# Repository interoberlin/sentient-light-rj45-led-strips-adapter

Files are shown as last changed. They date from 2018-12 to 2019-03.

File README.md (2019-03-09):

# sentient-light-rj45-led-strips-adapter

The adapter receives four data signals via an off-the-shelf RJ-45 ethernet socket
and routes them to a 1x5-pin header as well as to LED strip solder pads.
The adapter is intended for usage with strips of addressable LEDs (e.g. WS2812 or SK6812).

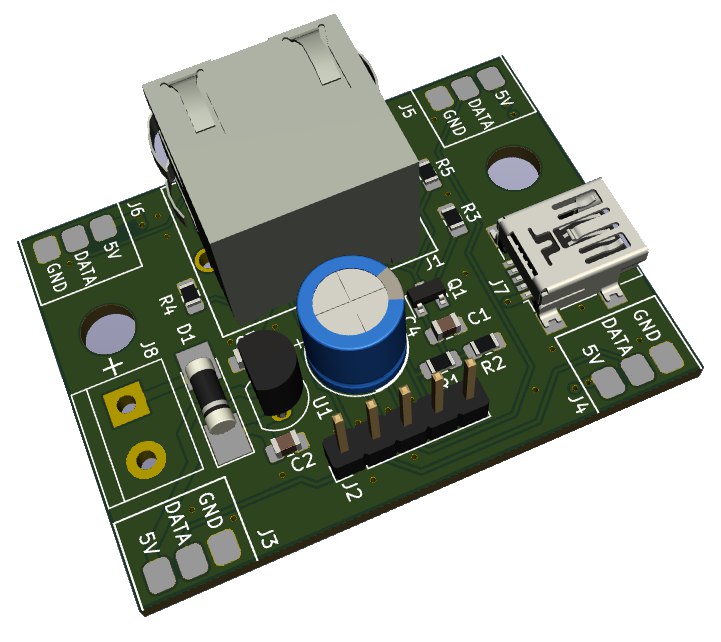
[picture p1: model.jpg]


## Original design goals

* The 1x5-pin header must match the pin layout previously used in this project:
  * https://github.com/interoberlin/Baumhaus-Tree-Adapter
* The RJ-45 socket pins assignment must match the one used in this project:
  * https://github.com/interoberlin/sentient-light-fpga-rj45-adapter
* The PCB should have holes suitable for (wall) mounting.
* It should be possible to attach a 5V supply to the board, e.g. via USB, screw socket or barrel jack socket.
* A high current-capable diode should protect against incorrect supply voltage polarization.
* One LED of the RJ-45 socket should announce the presence of the 5V supply voltage.
* The second LED should light up, when data is received on one of the four signal lines.
* Footprints should be present for one or more 5V LDOs (depending on the required LED current).

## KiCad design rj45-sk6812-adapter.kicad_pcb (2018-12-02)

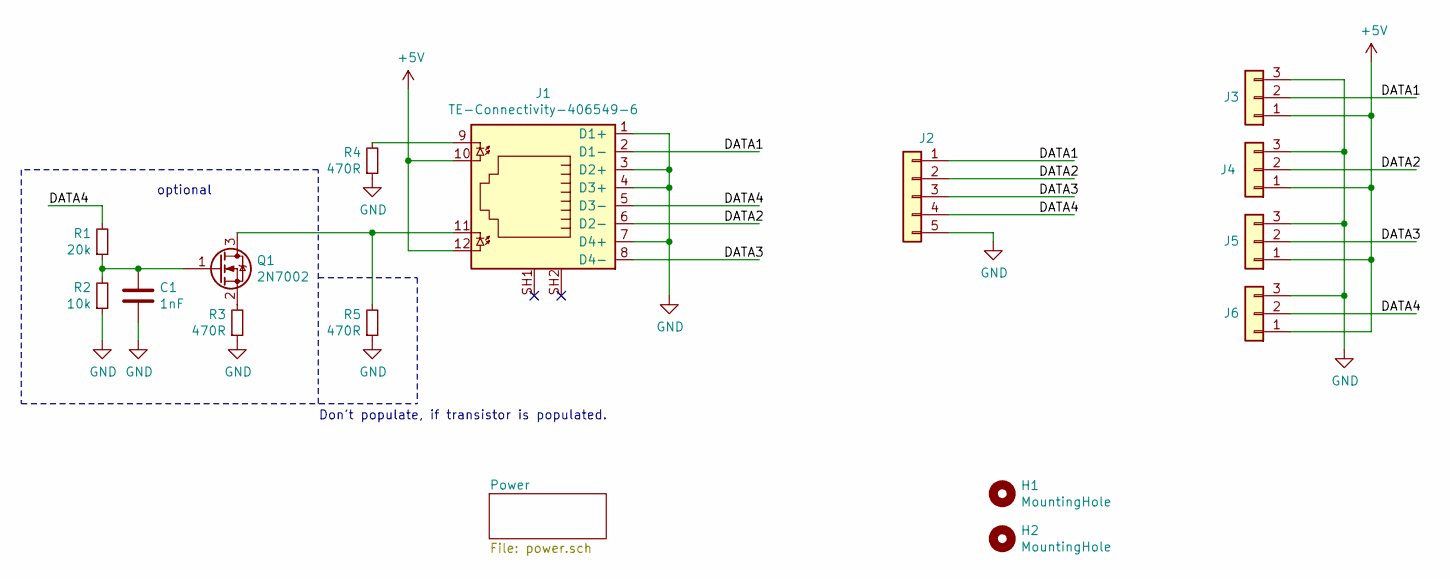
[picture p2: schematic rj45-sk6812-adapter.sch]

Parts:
C1: 1nF; C_0805_2012Metric_Pad1.15x1.40mm_HandSolder
H1, H2: MountingHole; MountingHole_4.5mm
J1: TE-Connectivity-406549-6
J2: Conn_01x05; PinHeader_1x05_P2.54mm_Vertical
J3, J4, J5, J6: Conn_01x03; WS6812-SK6812
Q1: 2N7002; SOT-23
R1: 20k; R_0805_2012Metric_Pad1.15x1.40mm_HandSolder
R2: 10k; R_0805_2012Metric_Pad1.15x1.40mm_HandSolder
R3, R4, R5: 470R; R_0805_2012Metric_Pad1.15x1.40mm_HandSolder

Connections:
+5V: J1.10, J1.12, J3.1, J4.1, J5.1, J6.1; also elsewhere on the board
/DATA1: J1.2 (D1-), J2.1, J3.2
/DATA2: J1.6 (D2-), J2.2, J4.2
/DATA3: J1.8 (D4-), J2.3, J5.2
/DATA4: J1.5 (D3-), J2.4, J6.2, R1.2
GND: C1.2, J1.1 (D1+), J1.3 (D2+), J1.4 (D3+), J1.7 (D4+), J2.5, J3.3, J4.3, J5.3, J6.3, R2.1, R3.1, R4.1, R5.1; also elsewhere on the board
unnamed: C1.1, Q1.1 (G), R1.1, R2.2
unnamed: J1.9, R4.2
unnamed: J1.11, Q1.3 (D), R5.2
unnamed: Q1.2 (S), R3.2

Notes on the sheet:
optional
Don't populate, if transistor is populated.

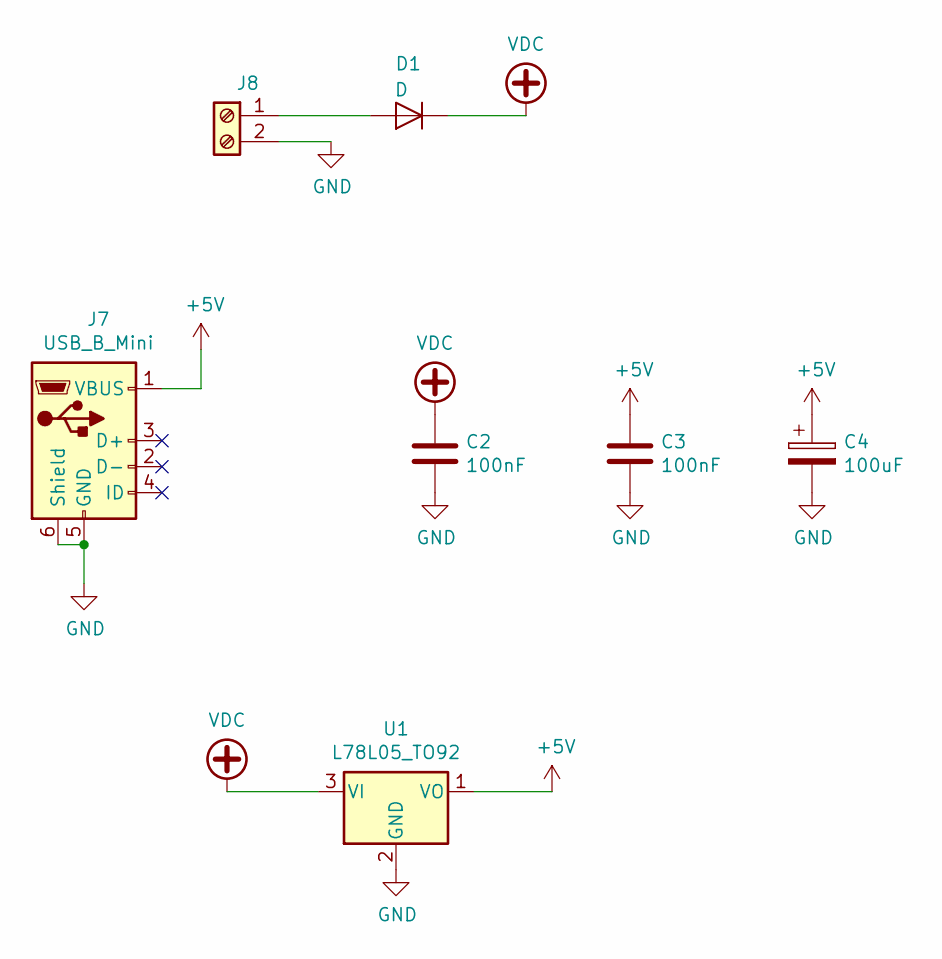
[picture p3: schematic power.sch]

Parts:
C2, C3: 100nF; C_0805_2012Metric_Pad1.15x1.40mm_HandSolder
C4: 100uF; CP_Radial_D8.0mm_P3.80mm
D1: D; D_MELF_Handsoldering
J7: USB_B_Mini; USB_Mini-B_Lumberg_2486_01_Horizontal
J8: Screw_Terminal_01x02; TerminalBlock_bornier-2_P5.08mm
U1: L78L05_TO92; TO-92_Inline

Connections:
+5V: C3.1, C4.1, J7.1 (VBUS), U1.1 (VO); also elsewhere on the board
GND: C2.2, C3.2, C4.2, J7.5 (GND), J7.6 (Shield), J8.2, U1.2 (GND); also elsewhere on the board
unnamed: D1.2 (A), J8.1
VDC: C2.1, D1.1 (K), U1.3 (VI)

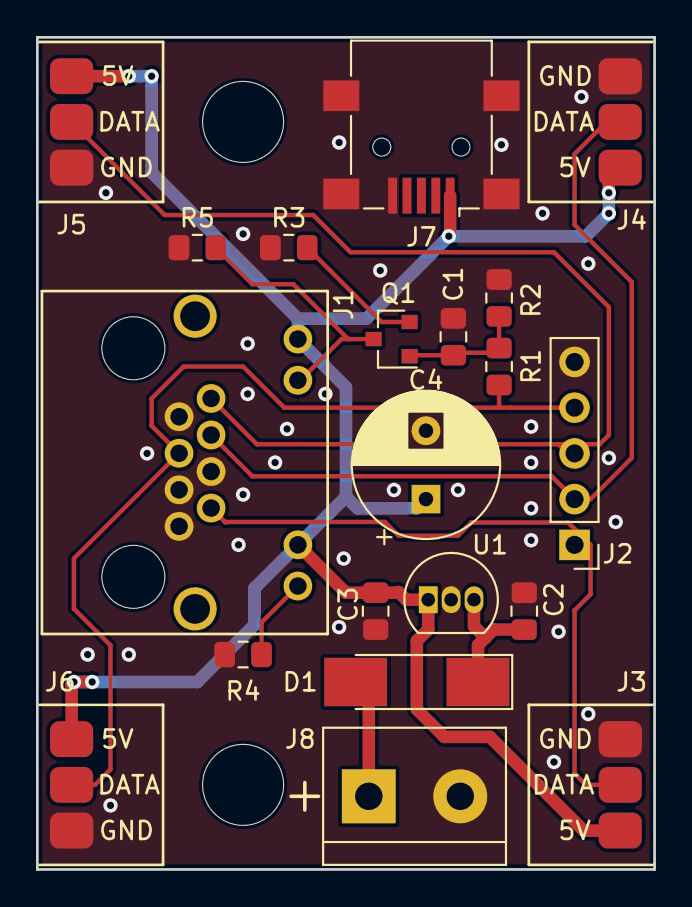
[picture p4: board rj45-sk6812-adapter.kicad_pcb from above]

Board: 2 copper layers, 34.3 x 46.2 mm, 22 parts (0 on the bottom side), 12 nets.

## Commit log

2018-10-25 Completed schematic
    [rj45-sk6812-adapter.kicad_pcb, rj45-sk6812-adapter.sch]
2018-10-25 Added mini-USB socket
    [rj45-sk6812-adapter.sch]
2018-10-25 Finished layouting
    [rj45-sk6812-adapter.kicad_pcb, rj45-sk6812-adapter.sch]
2018-11-27 Added my KiCad libraries as submodule
2018-11-27 Using the correct RJ-45 socket
    Added LED resistor and capacitor
    [rj45-sk6812-adapter.sch]
2018-12-02 Finished layouting
    Added an optional circuit to blink an LED during data transmission
    and a diode protected and 5V regulated power supply connector.
    [power.sch, rj45-sk6812-adapter.kicad_pcb, rj45-sk6812-adapter.sch]
2018-12-02 Exported fabrication files
    [rj45-sk6812-adapter-B.Cu.gbl, rj45-sk6812-adapter-B.Mask.gbs, rj45-sk6812-adapter-B.SilkS.gbo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]
2018-12-02 Added capacitor to stabilize the LEDs' 5V supply
    [power.sch, rj45-sk6812-adapter.kicad_pcb]
